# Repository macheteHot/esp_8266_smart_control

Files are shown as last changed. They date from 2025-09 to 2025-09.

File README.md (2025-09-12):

# ESP8266-IR-SmartControl 智能家居控制器

## 项目简介

本项目基于 ESP8266 接入 Home Assistant，旨在实现智能家居控制功能，包括红外空调遥控、门磁传感、灯光控制、存在感应、射频波控制、MQTT 通信、Web 控制界面等。适用于房间自动化、远程控制和状态监测。

## 主要功能

- 红外遥控设备控制
- 门磁传感器检测门的开关状态
- 灯光自动/手动控制
- 人体存在传感器检测
- 射频波设备控制
- MQTT 协议远程通信
- Web Server 提供网页控制界面
- WiFi 配网与联网
- 433 信号发送到 mqtt 可通过 home assistant 自动化处理

## 快速开始

1. ## **硬件准备**：

   - 通过 `hardware/Gerber.zip` 下单 PCB
   - 通过 `hardware/bom.xlsx` 购买电子元件
   - 自行购买 门磁、随意贴、人体感应等传感器
   - 按照 `hardware/` 目录下的电路图组装

   **硬件实物与渲染图展示：**
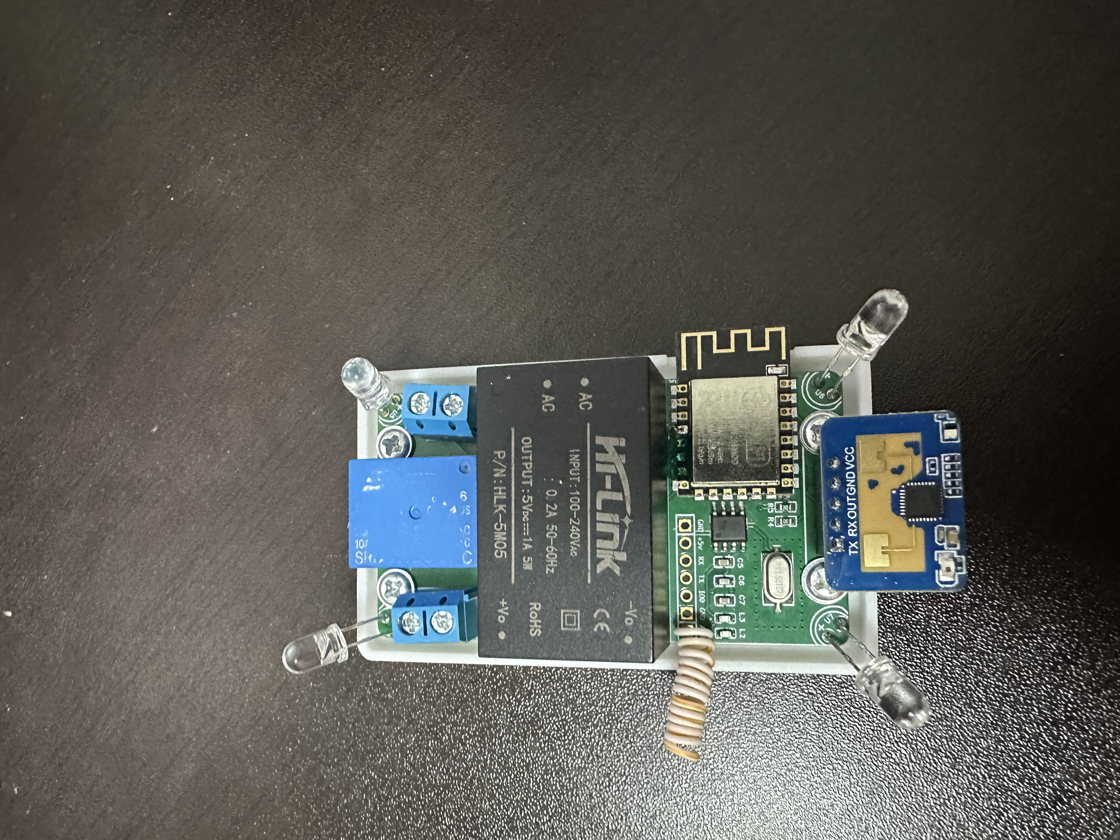
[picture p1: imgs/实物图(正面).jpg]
实物图
   
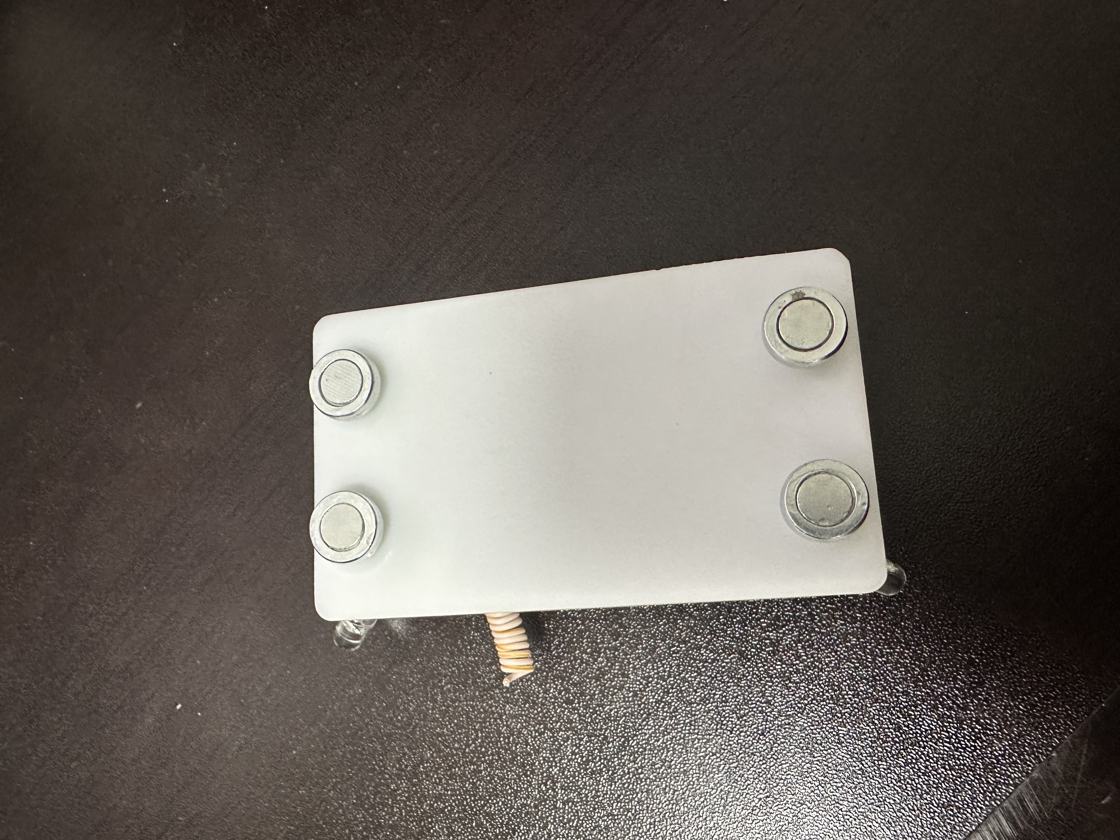
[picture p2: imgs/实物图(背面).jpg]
实物图背面
   
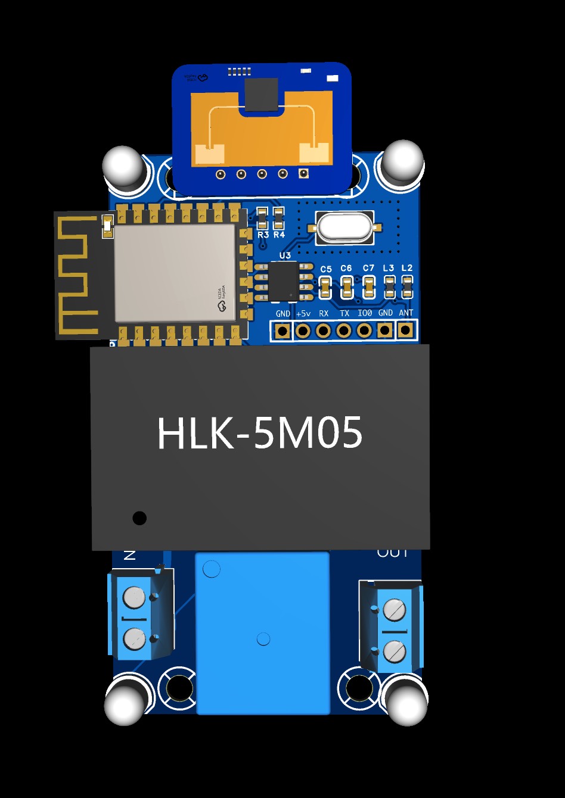
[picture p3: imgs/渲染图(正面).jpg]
渲染图
   
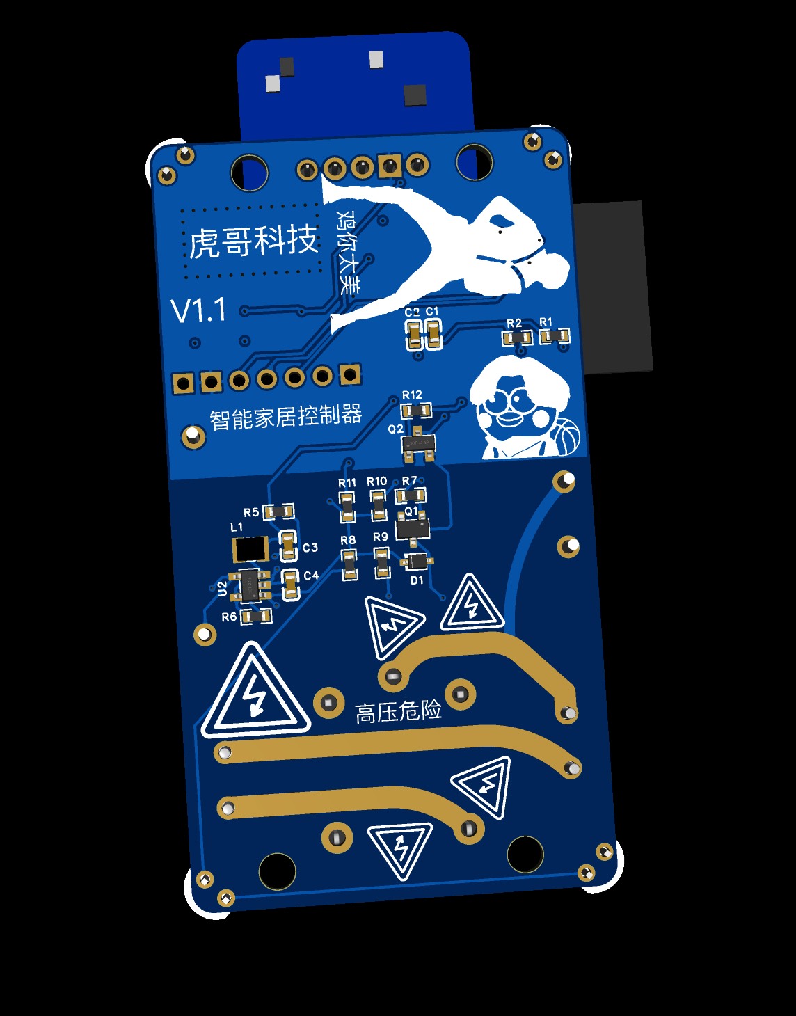
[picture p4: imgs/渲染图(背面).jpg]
渲染图背面
   
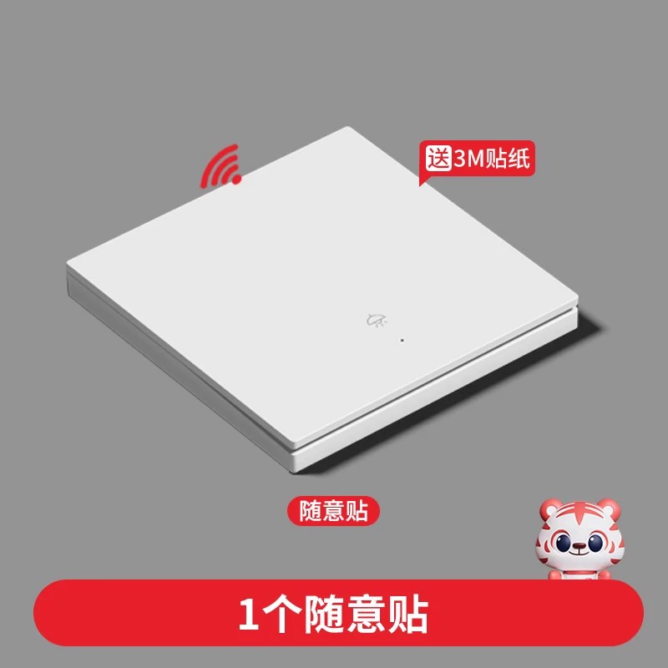
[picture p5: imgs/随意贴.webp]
随意贴
   
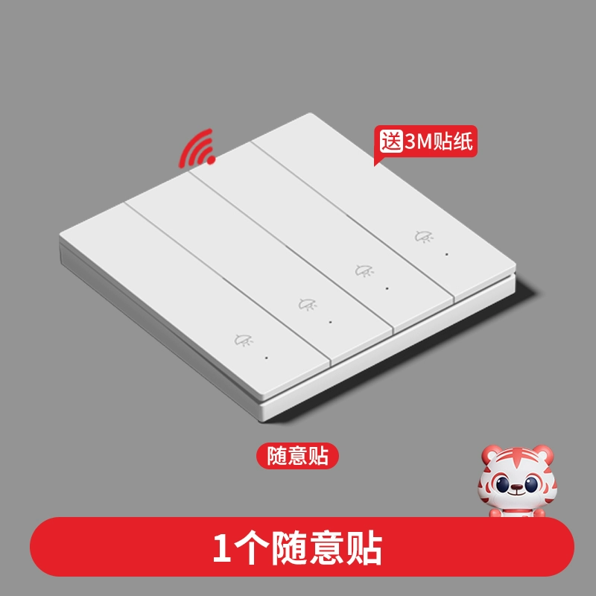
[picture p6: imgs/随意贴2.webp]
随意贴2
   
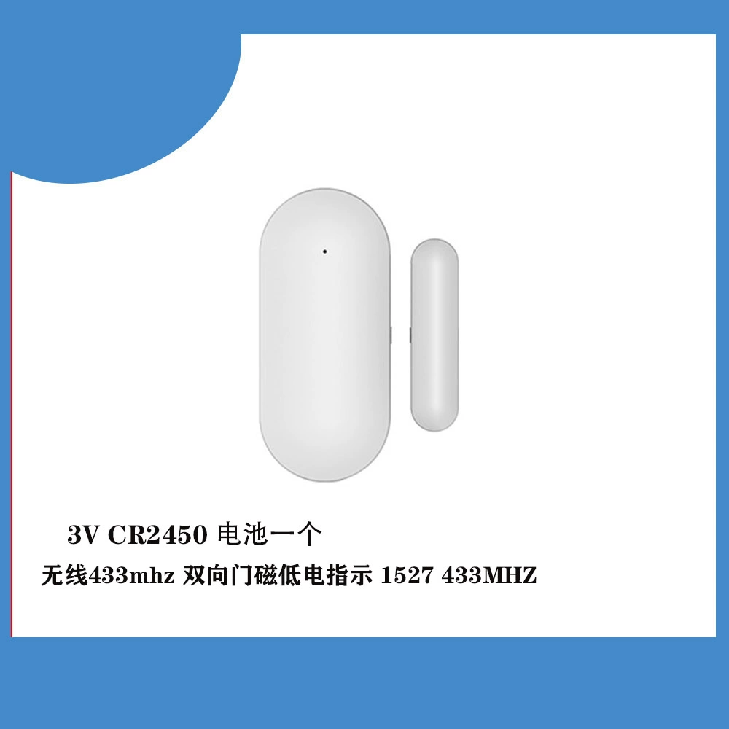
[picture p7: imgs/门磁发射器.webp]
   
   更多硬件资料见 `hardware/` 目录，包括 3D 打印外壳、原理图、BOM、Gerber 文件等。

   **天线制作说明：**

   - 建议使用 17.3cm 长的网线单根（铜芯线）绕制 433mhz 天线，一端焊接到 PCB 天线焊盘，另一端悬空。

2. **网页控制**：

   - 设备联网后，访问设备 IP 即可打开网页控制界面 控制页面可以选择开启的功能
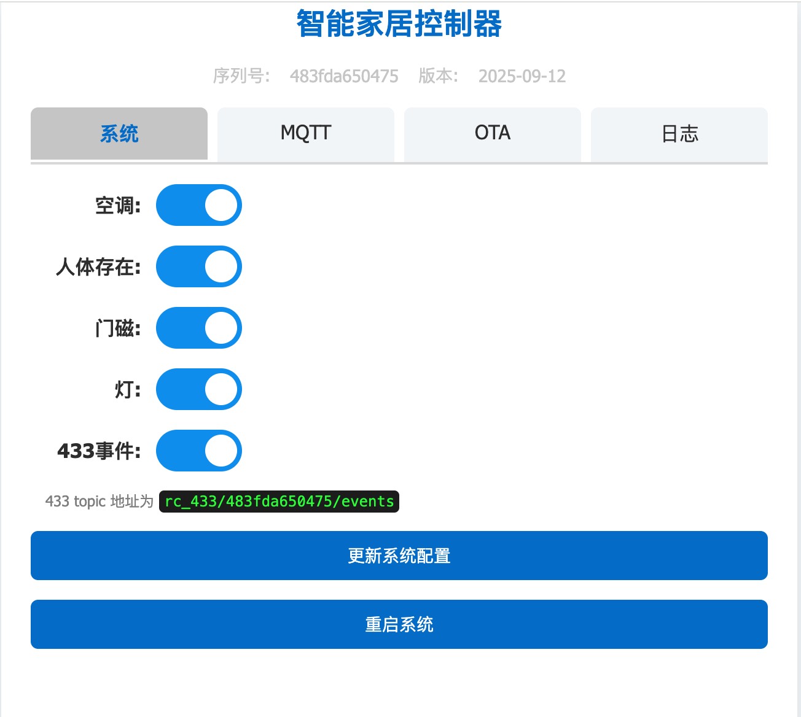
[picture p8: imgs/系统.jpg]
系统
     
   - 可在 mqtt 或初始化配网页面配置服务器地址密码等
   - 可在 HomeAssistant 自动化处接收 433 事件
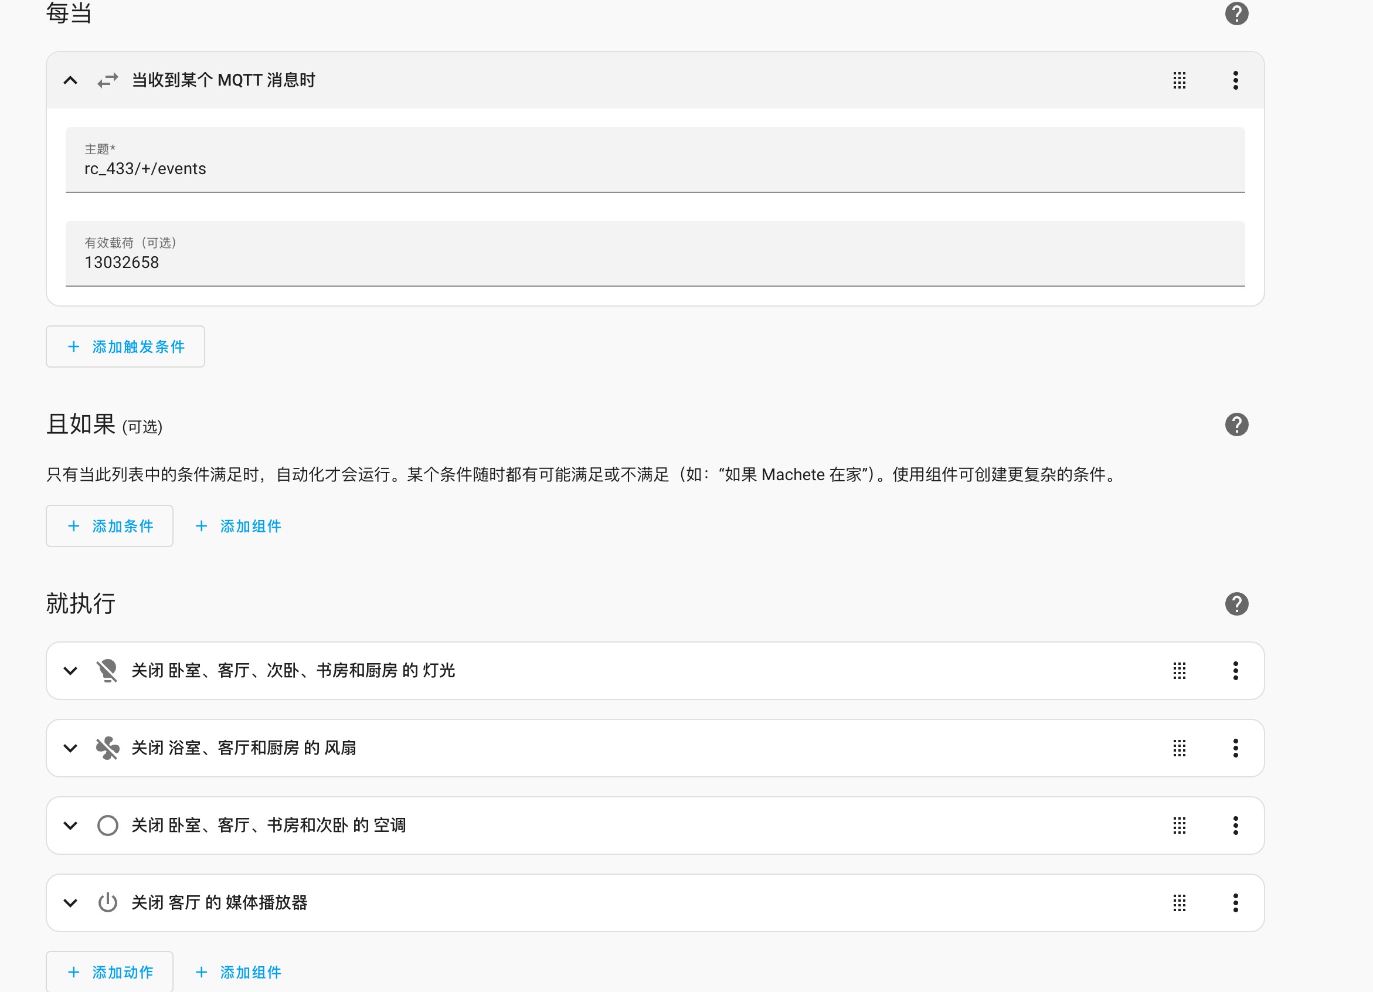
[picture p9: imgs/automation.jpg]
automation
     
   - 可在 OTA 页面上传固件升级
   - 可在日志页面看到系统日志和 433 无线设备码
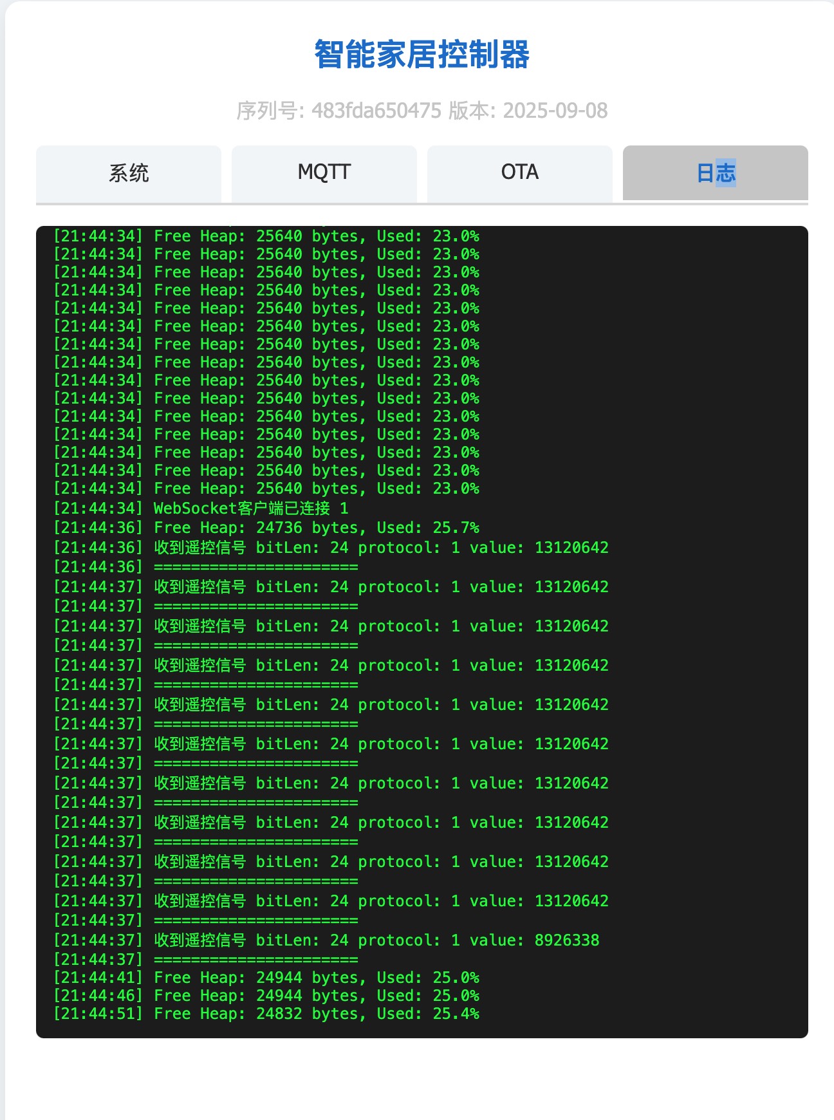
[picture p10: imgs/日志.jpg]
日志
     

3. **Home Assistant 无线电配置**：

   - 本项目通过 MQTT 与 Home Assistant 集成。
   - 可在 Home Assistant 配置页面调整空调型号
   - 可在 Home Assistant 的配置页面添加 433MHz 无线电控制设备，实现远程开关灯、空调、门磁等。

   **Home Assistant 配置页面示例：**
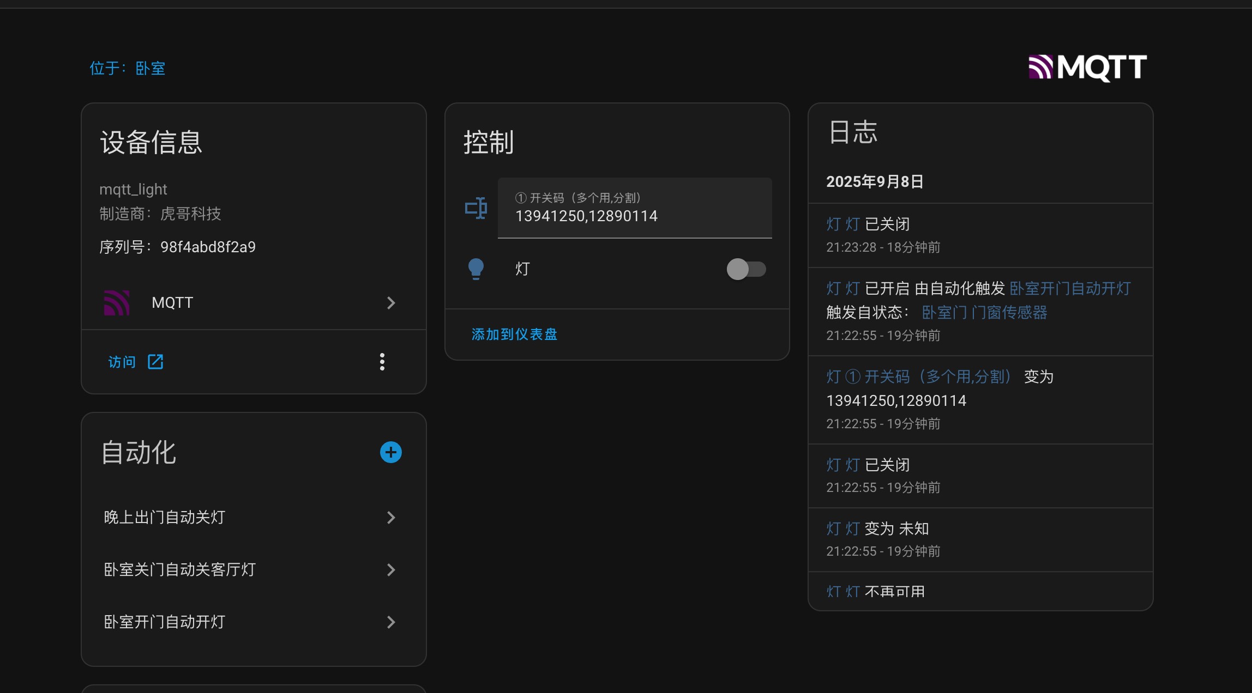
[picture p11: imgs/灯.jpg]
灯
   
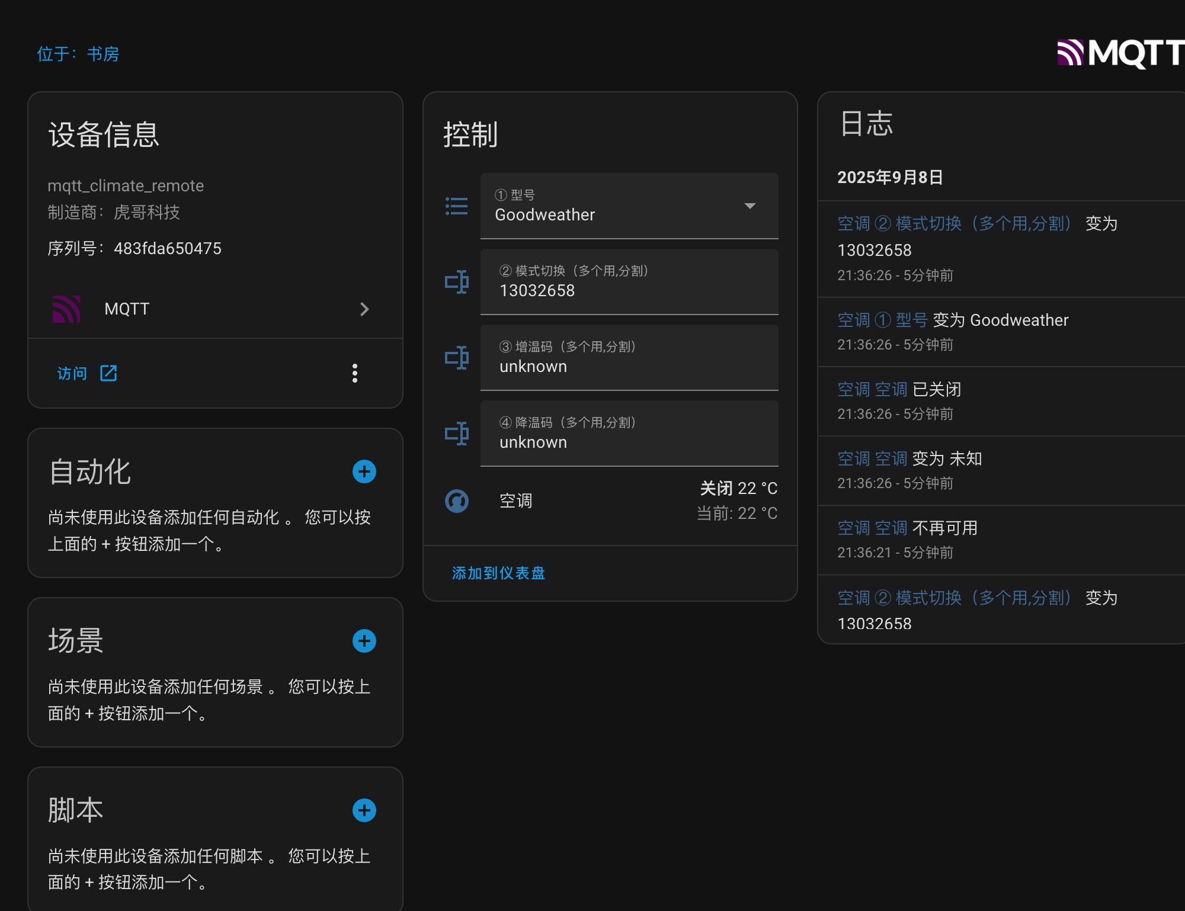
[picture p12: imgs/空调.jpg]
空调
   
   门磁

## 贡献

欢迎提交 issue 和 PR 参与项目改进。

## License

MIT

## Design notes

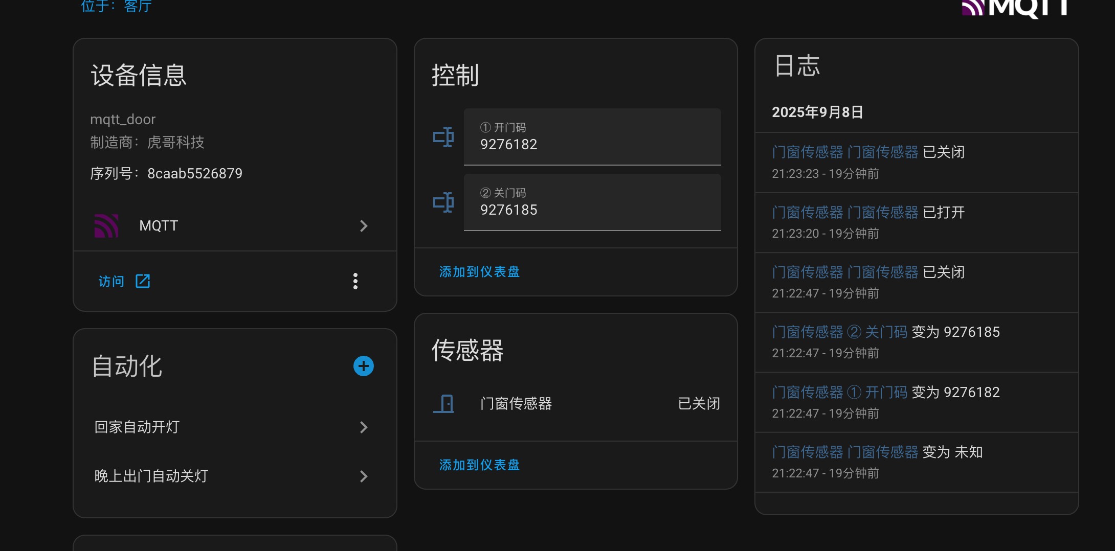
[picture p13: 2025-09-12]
imgs/门磁.jpg

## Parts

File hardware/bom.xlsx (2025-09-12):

No. | Quantity | Comment | Designator | Footprint | Value | Manufacturer Part | Manufacturer | Supplier Part | Supplier
1 | 1 | 10uF | C1 | C0603 | 10uF | CL10A106KP8NNNC | SAMSUNG(三星) | C19702 | LCSC
2 | 2 | 100nF | C2,C7 | C0603 | 100nF | CC0603KRX7R9BB104 | YAGEO(国巨) | C14663 | LCSC
3 | 1 | 15pF | C3 | C0603 | 15pF | CL10C150JB8NNNC | SAMSUNG(三星) | C1644 | LCSC
4 | 1 | 22uF | C4 | C0603 | 22uF | CL10A226MO7JZNC | SAMSUNG(三星) | C2762594 | LCSC
5 | 1 | 2.4pF | C5 | C0603 | 2.4pF | 0603CG2R4C500NT | FH(风华) | C27741 | LCSC
6 | 1 | 6pF | C6 | C0603 | 6pF | 0603CG6R0C500NT | FH(风华) | C37474 | LCSC
7 | 1 | 1N5819WS(SL) | D1 | SOD-323_L1.7-W1.3-LS2.7-RD |  | 1N5819WS(SL) | KEXIN(科信) | C489147 | LCSC
8 | 1 | 2.2uH | L1 | IND-SMD_L2.5-W2.0_MHCHL2520 | 2.2uH | FTC252012S2R2MBCA | cjiang(长江微电) | C5832372 | LCSC
9 | 1 | 27nH | L2 | L0603 | 27nH | VHF160808H27NJT | FH(风华) | C90208 | LCSC
10 | 1 | 33nH | L3 | L0603 | 33nH | SCHF160808H33NJT | Yanchuang(研创) | C577999 | LCSC
11 | 2 | KF301-2P接线端子 | P1,P2 | CONN-TH_XY301V-A-5.0-2P |  | KF301-2P接线端子 |  | C9900016950 | LCSC
12 | 2 | S8050 J3Y(RANGE:200-350) | Q1,Q2 | SOT-23-3_L3.0-W1.7-P0.95-LS2.9-BR |  | S8050 J3Y(RANGE:200-350) | CJ(江苏长电/长晶) | C2146 | LCSC
13 | 4 | 10kΩ | R1,R2,R3,R4 | R0603 | 10kΩ | 0603WAF1002T5E | UNI-ROYAL(厚声) | C25804 | LCSC
14 | 1 | 453kΩ | R5 | R0603 | 453kΩ | FRC0603F4533TS | FOJAN(富捷) | C3013202 | LCSC
15 | 1 | 100kΩ | R6 | R0603 | 100kΩ | 0603WAF1003T5E | UNI-ROYAL(厚声) | C25803 | LCSC
16 | 1 | 1kΩ | R7 | R0603 | 1kΩ | 0603WAF1001T5E | UNI-ROYAL(厚声) | C21190 | LCSC
17 | 4 | 49.9Ω | R8,R9,R10,R11 | R0603 | 49.9Ω | 0603WAF499JT5E | UNI-ROYAL(厚声) | C23185 | LCSC
18 | 1 | 1kΩ | R12 | R0603 | 1kΩ | 0603WAF1000T5E | UNI-ROYAL(厚声) |  | LCSC
19 | 1 | SRD-05VDC-SL-C | RLY1 | RELAY-TH_SRD-XXVDC-XL-C |  | SRD-05VDC-SL-C | 松乐 | C35449 | LCSC
20 | 1 | HLK-LD2410C-P | SM1 | SENSOR-TH_HLK-LD2410C-P |  | HLK-LD2410C-P | HI-LINK(海凌科) | C19723500 | LCSC
21 | 1 | 2.4GHz | U1 | WIFIM-SMD_ESP-12F-ESP8266MOD | 2.4GHz | ESP-12F(ESP8266MOD) | Ai-Thinker(安信可) | C82891 | LCSC
22 | 1 | TLV62568DBVR | U2 | SOT-23-5_L3.0-W1.7-P0.95-LS2.8-BR |  | TLV62568DBVR | TI(德州仪器) | C163219 | LCSC
23 | 1 | WF480RA H VL2.8mA S8T&R | U3 | SOP-8_L4.9-W3.9-P1.27-LS6.0-BL |  | WF480RA H VL2.8mA S8T&R | WF(伟烽) | C7434470 | LCSC
24 | 4 | IR333C-F-A | U4,U5,U6,U7 | LED-TH_BD6.2-P2.54-FD |  | IR333C-F-A | EVERLIGHT(亿光) | C264288 | LCSC
25 | 1 | HLK-5M05 | U8 | PWRM-TH_HLK-5M05 |  | HLK-5M05 | HI-LINK(海凌科) | C209907 | LCSC
26 | 1 | 13.52127MHz | X1 | CRYSTAL-SMD_L7.0-W4.0-LS7.8 | 13.52127MHz | 13.52127M 20PF 10PPM | SST(索斯特) | C5289698 | LCSC

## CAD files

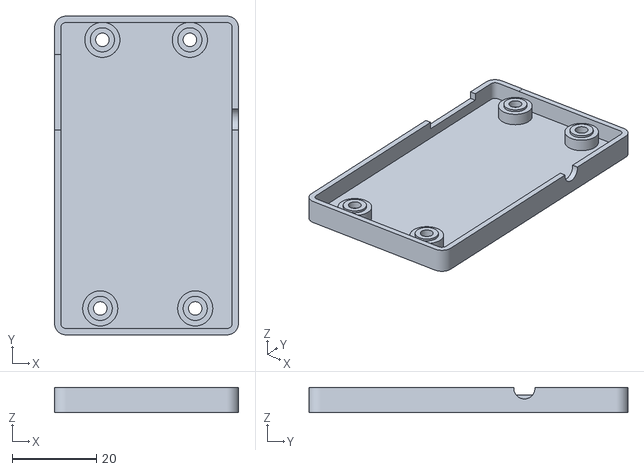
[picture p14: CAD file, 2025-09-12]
hardware/3D打印外壳.stl
43.7 x 75.7 x 6.00

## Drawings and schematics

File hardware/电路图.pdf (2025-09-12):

电源

# 433接收器

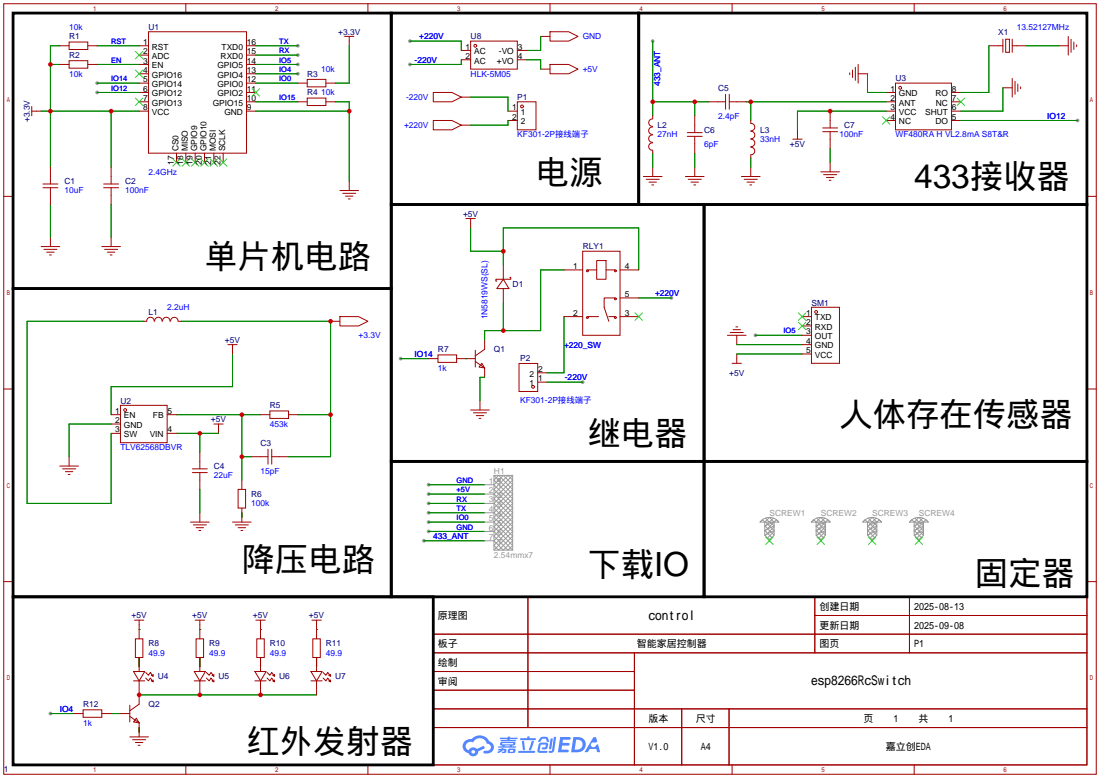
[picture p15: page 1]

原理图 | control | 创建日期 | 2025-08-13

更新日期 | 2025-09-08

板子 | 智能家居控制器 | 图页 | P1

绘制 | | esp8266RcSwitch
审阅

V1.0 | A4 | 嘉立创EDA

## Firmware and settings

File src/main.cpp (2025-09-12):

#include <Arduino.h>
#include <TaskScheduler.h>

Scheduler runner; // 主调度器

void sendLog(const String &msg);
void loadAllConfig();
void syncTimeFromNtpList();
void autoConnectWifi();
void initLED();
void initMqtt();
void initRadioReceiver();
void blinkLED(int times);
void initWebServer();
String getLocalUrl();

String configPageUrl = "";

uint32_t initialHeap = 0;

void sendFreeHeap() {
  uint32_t freeHeap = ESP.getFreeHeap();
  float usedPercent = (float)(initialHeap - freeHeap) * 100.0 / initialHeap;
  sendLog("Free Heap: " + String(freeHeap) +
          " bytes, Used: " + String(usedPercent, 1) + "%");
}

Task logFreeHeapTask(5000, TASK_FOREVER, &sendFreeHeap);

void setup() {
  Serial.begin(115200);
  initialHeap = ESP.getFreeHeap(); // 记录最大内存
  loadAllConfig();                 // 获取所有配置 最早初始化
  initLED();
  autoConnectWifi();             // 最早先连接wifi
  configPageUrl = getLocalUrl(); // 获取本机地址
  blinkLED(3);                   // wifi 连接成功 闪烁 LED
  syncTimeFromNtpList();         // 时间同步
  initRadioReceiver();           // 初始化433 无线电
  initMqtt();                    // 初始化mqtt通信
  initWebServer();               // 开启web 服务
  runner.addTask(logFreeHeapTask);
  logFreeHeapTask.enable();
}

// ==== 主循环 ====
void loop() { runner.execute(); }

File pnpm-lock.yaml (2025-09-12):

lockfileVersion: '9.0'

settings:
  autoInstallPeers: true
  excludeLinksFromLockfile: false

importers:

  .:
    devDependencies:
      '@rollup/plugin-replace':
        specifier: ^6.0.2
        version: 6.0.2(rollup@4.49.0)
      '@rollup/plugin-terser':
        specifier: ^0.4.4
        version: 0.4.4(rollup@4.49.0)
      clean-css:
        specifier: ^5.3.3
        version: 5.3.3
      gzipper:
        specifier: ^8.2.1
        version: 8.2.1
      html-minifier-terser:
        specifier: ^7.2.0
        version: 7.2.0
      rollup:
        specifier: ^4.49.0
        version: 4.49.0
      rollup-plugin-postcss:
        specifier: ^4.0.2
        version: 4.0.2(postcss@8.5.6)

packages:

  '@gfx/zopfli@1.0.15':
    resolution: {integrity: sha512-7mBgpi7UD82fsff5ThQKet0uBTl4BYerQuc+/qA1ELTwWEiIedRTcD3JgiUu9wwZ2kytW8JOb165rSdAt8PfcQ==}
    engines: {node: '>= 8'}

  '@jridgewell/gen-mapping@0.3.13':
    resolution: {integrity: sha512-2kkt/7niJ6MgEPxF0bYdQ6etZaA+fQvDcLKckhy1yIQOzaoKjBBjSj63/aLVjYE3qhRt5dvM+uUyfCg6UKCBbA==}

  '@jridgewell/resolve-uri@3.1.2':
    resolution: {integrity: sha512-bRISgCIjP20/tbWSPWMEi54QVPRZExkuD9lJL+UIxUKtwVJA8wW1Trb1jMs1RFXo1CBTNZ/5hpC9QvmKWdopKw==}
    engines: {node: '>=6.0.0'}

  '@jridgewell/source-map@0.3.11':
    resolution: {integrity: sha512-ZMp1V8ZFcPG5dIWnQLr3NSI1MiCU7UETdS/A0G8V/XWHvJv3ZsFqutJn1Y5RPmAPX6F3BiE397OqveU/9NCuIA==}

  '@jridgewell/sourcemap-codec@1.5.5':
    resolution: {integrity: sha512-cYQ9310grqxueWbl+WuIUIaiUaDcj7WOq5fVhEljNVgRfOUhY9fy2zTvfoqWsnebh8Sl70VScFbICvJnLKB0Og==}

  '@jridgewell/trace-mapping@0.3.30':
    resolution: {integrity: sha512-GQ7Nw5G2lTu/BtHTKfXhKHok2WGetd4XYcVKGx00SjAk8GMwgJM3zr6zORiPGuOE+/vkc90KtTosSSvaCjKb2Q==}

  '@rollup/plugin-replace@6.0.2':
    resolution: {integrity: sha512-7QaYCf8bqF04dOy7w/eHmJeNExxTYwvKAmlSAH/EaWWUzbT0h5sbF6bktFoX/0F/0qwng5/dWFMyf3gzaM8DsQ==}
    engines: {node: '>=14.0.0'}
    peerDependencies:
      rollup: ^1.20.0||^2.0.0||^3.0.0||^4.0.0
    peerDependenciesMeta:
      rollup:
        optional: true

  '@rollup/plugin-terser@0.4.4':
    resolution: {integrity: sha512-XHeJC5Bgvs8LfukDwWZp7yeqin6ns8RTl2B9avbejt6tZqsqvVoWI7ZTQrcNsfKEDWBTnTxM8nMDkO2IFFbd0A==}
    engines: {node: '>=14.0.0'}
    peerDependencies:
      rollup: ^2.0.0||^3.0.0||^4.0.0
    peerDependenciesMeta:
      rollup:
        optional: true

  '@rollup/pluginutils@5.2.0':
    resolution: {integrity: sha512-qWJ2ZTbmumwiLFomfzTyt5Kng4hwPi9rwCYN4SHb6eaRU1KNO4ccxINHr/VhH4GgPlt1XfSTLX2LBTme8ne4Zw==}
    engines: {node: '>=14.0.0'}
    peerDependencies:
      rollup: ^1.20.0||^2.0.0||^3.0.0||^4.0.0
    peerDependenciesMeta:
      rollup:
        optional: true

  '@rollup/rollup-android-arm-eabi@4.49.0':
    resolution: {integrity: sha512-rlKIeL854Ed0e09QGYFlmDNbka6I3EQFw7iZuugQjMb11KMpJCLPFL4ZPbMfaEhLADEL1yx0oujGkBQ7+qW3eA==}
    cpu: [arm]
    os: [android]

  '@rollup/rollup-android-arm64@4.49.0':
    resolution: {integrity: sha512-cqPpZdKUSQYRtLLr6R4X3sD4jCBO1zUmeo3qrWBCqYIeH8Q3KRL4F3V7XJ2Rm8/RJOQBZuqzQGWPjjvFUcYa/w==}
    cpu: [arm64]
    os: [android]

  '@rollup/rollup-darwin-arm64@4.49.0':
    resolution: {integrity: sha512-99kMMSMQT7got6iYX3yyIiJfFndpojBmkHfTc1rIje8VbjhmqBXE+nb7ZZP3A5skLyujvT0eIUCUsxAe6NjWbw==}
    cpu: [arm64]
    os: [darwin]

  '@rollup/rollup-darwin-x64@4.49.0':
    resolution: {integrity: sha512-y8cXoD3wdWUDpjOLMKLx6l+NFz3NlkWKcBCBfttUn+VGSfgsQ5o/yDUGtzE9HvsodkP0+16N0P4Ty1VuhtRUGg==}
    cpu: [x64]
    os: [darwin]

  '@rollup/rollup-freebsd-arm64@4.49.0':
    resolution: {integrity: sha512-3mY5Pr7qv4GS4ZvWoSP8zha8YoiqrU+e0ViPvB549jvliBbdNLrg2ywPGkgLC3cmvN8ya3za+Q2xVyT6z+vZqA==}
    cpu: [arm64]
    os: [freebsd]

  '@rollup/rollup-freebsd-x64@4.49.0':
    resolution: {integrity: sha512-C9KzzOAQU5gU4kG8DTk+tjdKjpWhVWd5uVkinCwwFub2m7cDYLOdtXoMrExfeBmeRy9kBQMkiyJ+HULyF1yj9w==}
    cpu: [x64]
    os: [freebsd]

  '@rollup/rollup-linux-arm-gnueabihf@4.49.0':
    resolution: {integrity: sha512-OVSQgEZDVLnTbMq5NBs6xkmz3AADByCWI4RdKSFNlDsYXdFtlxS59J+w+LippJe8KcmeSSM3ba+GlsM9+WwC1w==}
    cpu: [arm]
    os: [linux]
    libc: [glibc]

  '@rollup/rollup-linux-arm-musleabihf@4.49.0':
    resolution: {integrity: sha512-ZnfSFA7fDUHNa4P3VwAcfaBLakCbYaxCk0jUnS3dTou9P95kwoOLAMlT3WmEJDBCSrOEFFV0Y1HXiwfLYJuLlA==}
    cpu: [arm]
    os: [linux]
    libc: [musl]

  '@rollup/rollup-linux-arm64-gnu@4.49.0':
    resolution: {integrity: sha512-Z81u+gfrobVK2iV7GqZCBfEB1y6+I61AH466lNK+xy1jfqFLiQ9Qv716WUM5fxFrYxwC7ziVdZRU9qvGHkYIJg==}
    cpu: [arm64]
    os: [linux]
    libc: [glibc]

  '@rollup/rollup-linux-arm64-musl@4.49.0':
    resolution: {integrity: sha512-zoAwS0KCXSnTp9NH/h9aamBAIve0DXeYpll85shf9NJ0URjSTzzS+Z9evmolN+ICfD3v8skKUPyk2PO0uGdFqg==}
    cpu: [arm64]
    os: [linux]
    libc: [musl]

  '@rollup/rollup-linux-loongarch64-gnu@4.49.0':
    resolution: {integrity: sha512-2QyUyQQ1ZtwZGiq0nvODL+vLJBtciItC3/5cYN8ncDQcv5avrt2MbKt1XU/vFAJlLta5KujqyHdYtdag4YEjYQ==}
    cpu: [loong64]
    os: [linux]
    libc: [glibc]
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
